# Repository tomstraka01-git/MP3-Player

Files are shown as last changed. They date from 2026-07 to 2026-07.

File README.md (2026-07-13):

<p align="center">
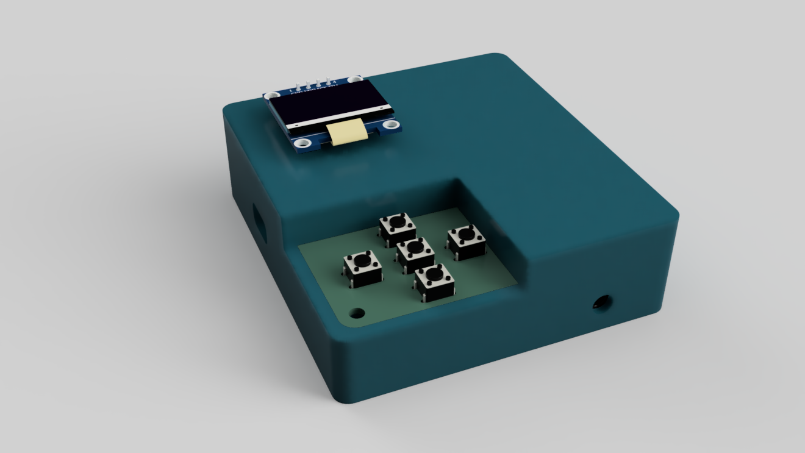
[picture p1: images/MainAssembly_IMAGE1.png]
  
</p>



# MP3-Player

## What is it?
MP3-Player is a DYI project made by me. It can:
- Play songs from a microSD card directly to your earphones.
- Stay on battery for multiple hours.
- Show you info about battery charge and info about song (time, song name, playing/not playing, etc.).
- Be controlled with 5 buttons.

## Why?
I like listening to music and making my own hardware/software projects, and i also wanted to learn more about how these things are made, so i chose to make one myself. 

## How to use?
1. Solder all the components to the custom PCB board.
2. 3D print the case and the battery hatch.
3. Screw the PCB securely into the case.
4. Download the firmware and flash it using the Arduino IDE.
5. Format a microSD card, add your `.mp3` or `.wav` songs directly to the root directory, and plug it into the reader.
6. Connect your charged Li-Po battery and you can now listen to your songs.

## Software
I wrote the main firmware in arduino ide c++. To flash the board, you must install arduino ide and the libraries i am using. Then connect the micro usb cable to the mcu, and flash the code. The code handles all the communications between the modules, plays the song to the PCM5102A and creates the ui, checks for buttons, checks battery etc.

## Electronics


I used a custom PCB, which takes power from a 3.7 Li-Po 450 mah (the battery should last for few hours) and passes it through a fast fuse for short circuit protection and diode for reverse connection protection. Then it goes to the rasberry pi pico 2 WH, which converts the power to stable 3.3V. The MCU reads the micro sd card reader module through spi, and then plays the song into the PCM5102A. It also displays all the info to the oled screen, and checks the five buttons for input. The five buttons have these features:
- Volume Down
- Volume Up
- Previous Song
- Next Song
- Play/Pause

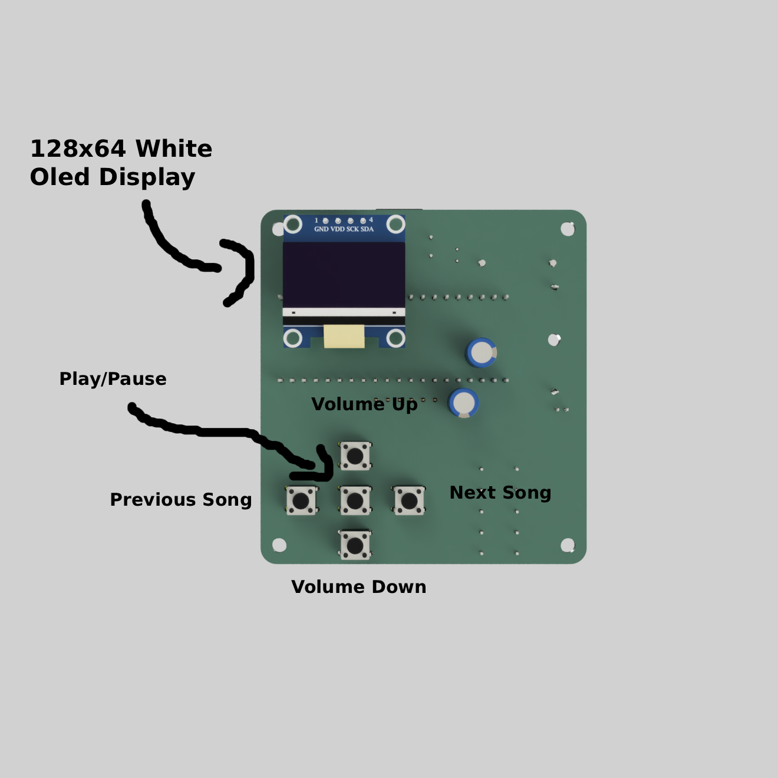
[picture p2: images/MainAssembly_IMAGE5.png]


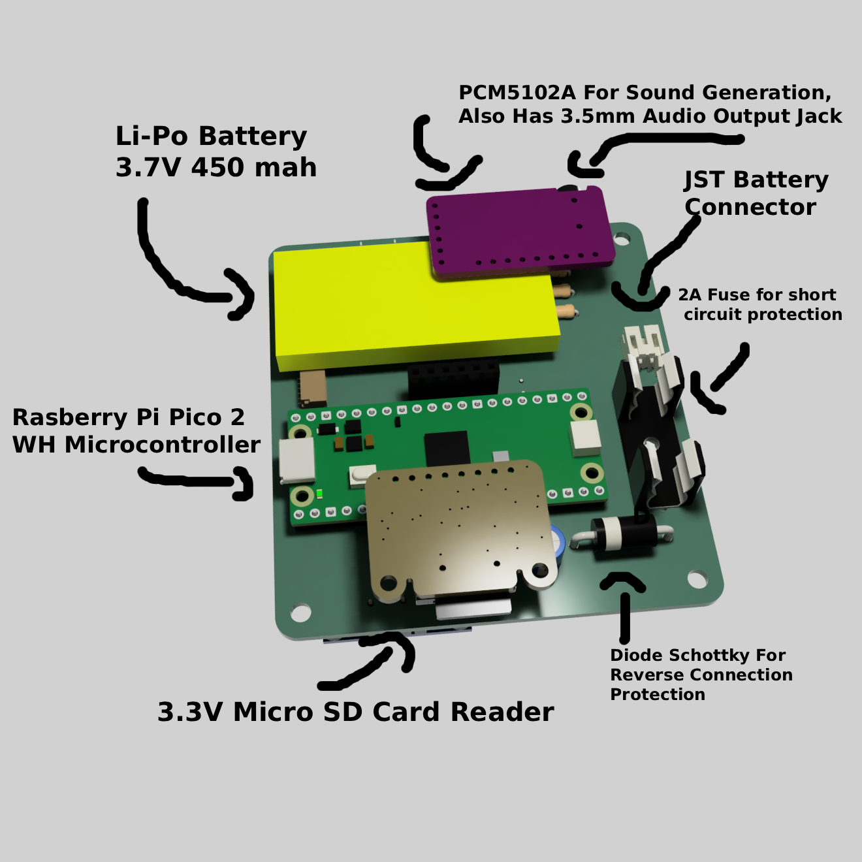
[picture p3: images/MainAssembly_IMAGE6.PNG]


## Features
- ### Has a 3.5mm audio jack output, you can connect your earphones to it and listen directly.
<p align="center">
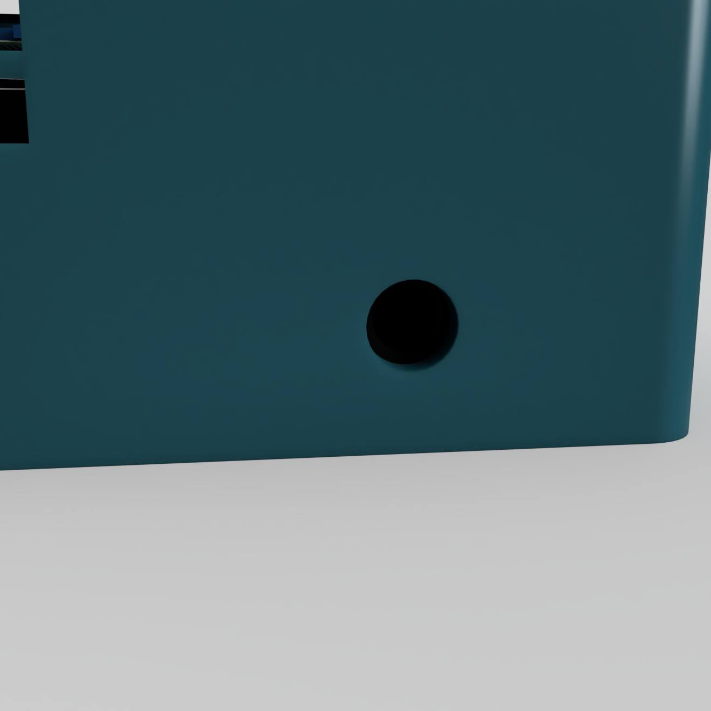
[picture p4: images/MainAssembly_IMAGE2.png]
  
</p>

- ### Has a micro SD card reader, put the micro SD card inside and listen to your songs.
<p align="center">
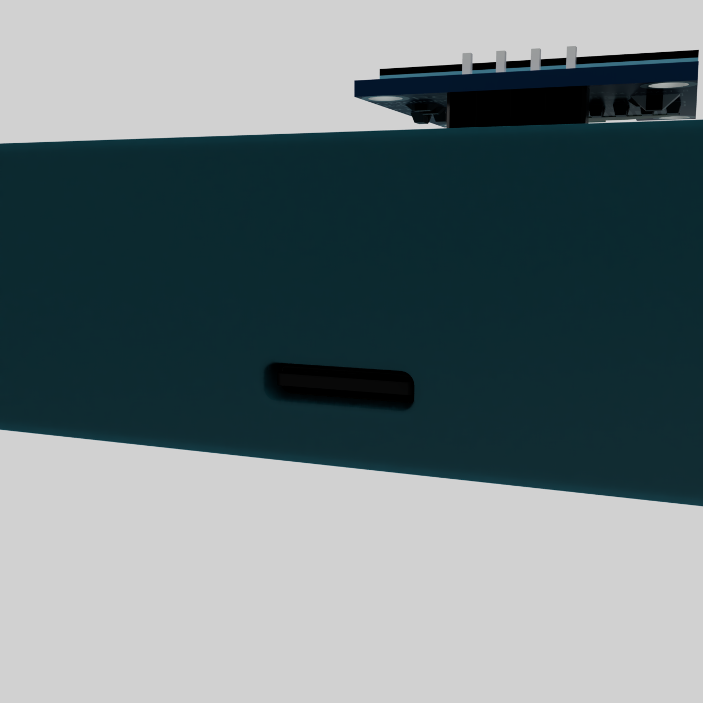
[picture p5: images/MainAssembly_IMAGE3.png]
  
</p>

- ### Has a micro USB port, so you can flash your own firmware or debug software issues.
<p align="center">
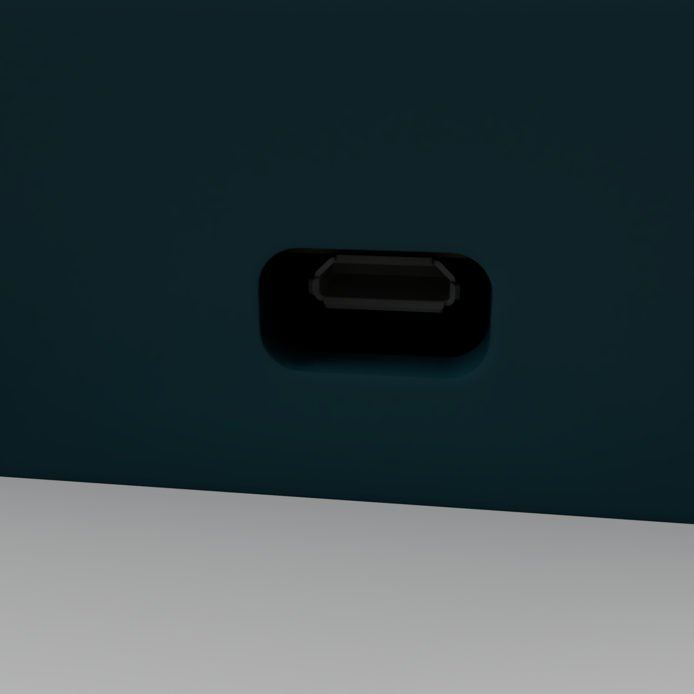
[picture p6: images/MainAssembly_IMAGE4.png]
  
</p>

# Bill of Materials (BOM)

| Item Name | Qty | Price (total) (USD) | Item Link | Notes |
|---|---|---|---|---|
| Resistor 10k | 5 | $0.24 | [Link](https://dratek.cz/arduino-platforma/7650-rezistor-10k-0.25-w-1.html) | Resistors for buttons, so that the circuit works |
| Button | 5 | $0.47 | [Link](https://dratek.cz/arduino-platforma/176310-mikrospinac-tlacitko-6-x-6-x-8-mm.html) | The buttons, used for skipping songs, changing volume, pausing, etc. |
| GY-PCM5102 I2S audio module | 1 | $4.61 | [Link](https://www.laskakit.cz/gy-pcm5102-i2s-audio-modul/) | The audio generator, changes digital sound to analog |
| 3.3V micro SD card module | 1 | $3.20 | [Link](https://www.laskakit.cz/laskakit-microsd-card-modul/) | Micro SD card reader, reads the micro SD card |
| OLED display 128x64 white | 1 | $7.86 | [Link](https://dratek.cz/arduino-platforma/3181-iic-i2c-oled-1-3-displej-128x64-bily.html) | OLED display, shows the user data like volume, info about songs, battery percent etc. |
| Resistor 100k | 1 | $0.05 | [Link](https://dratek.cz/arduino-platforma/7653-rezistor-100k-0.25-w-1.html) | Resistor for voltage divider, which steps down the voltage so the ADC can read it |
| Resistor 330k | 1 | $0.05 | [Link](https://dratek.cz/arduino-platforma/174965-metalizovany-rezistor-330k-0-25w-1.html) | Resistor for voltage divider, which steps down the voltage so the ADC can read it |
| Condensator 100µF 50V | 4 | $0.20 | [Link](https://dratek.cz/arduino-platforma/7825-kondenzator-100uf-50v.html) | Condensators, smooths the voltage and evens out current spikes |
| Fuse Fast 250V 2A | 10 | $0.19 | [Link](https://www.tme.eu/cz/details/zks-2a/pojistky-5x20mm-rychle/eska/520-620/) | Fast fuses — if there is a short circuit, the fuses blow and disconnect the battery from the circuit, protecting the battery and the person |
| Diode Schottky; THT; 40V; 3A; DO201AD; Ufmax: 0.475V | 2 | $0.64 | [Link](https://www.tme.eu/cz/details/1n5822-st/diody-schottky-tht/stmicroelectronics/1n5822/) | Diode, prevents opposite polarity battery connections |
| Dupont female pins | 1 | $0.33 | [Link](https://dratek.cz/arduino-platforma/913-dupont-dutinkova-lista-samice-samec.html?cv) | Used for plugging in the OLED display and other things |
| Dupont male pins | 1 | $0.15 | [Link](https://dratek.cz/arduino-platforma/1331-dupont-40pin-2-54-mm-kolikova-lista-rovna.html) | Same as above, but male version |
| JST 6-pin connector | 2 | $1.49 | [Link](https://www.tme.eu/cz/katalog/signalove-konektory-raster-1-00mm_112946/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) | SMD JST 6-pin connector, connects the micro SD card reader to the main PCB |
| JST 6-pin cable | 2 | $1.41 | [Link](https://dratek.cz/arduino-platforma/122186-jst-sh-1.0mm-6-pin-vodic-samice.html) | The cable for the SMD JST connector |
| Schurter fuse holder 10A 20x5mm | 2 | $2.28 | [Link](https://www.tme.eu/cz/details/0031.8211/pojistkova-pouzdra-do-pcb/schurter/) | Fuse holder — holds the fuse so it can be replaced when blown, no desoldering needed |
| JST battery terminal | 3 | $0.93 | [Link](https://www.tme.eu/cz/details/s2b-ph-k-s/signalove-konektory-raster-2-00mm/jst/s2b-ph-k-s-lf-sn/) | Battery terminal — the battery connects to it and distributes the power |
| Raspberry Pi Pico 2 WH | 1 | $9.71 | [Link](https://www.tme.eu/cz/details/sc1634/raspberry-pi-vestavene-systemy/raspberry-pi/raspberry-pi-pico-2-wh/) | The main brain of the system — reads the micro SD card, runs the UI menu, sends the sound output to the sound chip |
| Li-Po battery 3.7V 450mAh | 1 | $5.90 | [Link](https://dratek.cz/arduino-platforma/179445-lipol-baterie-502248-450mah-3-7v.html) | Shipping to Czech Republic |
| JLCPCB PCB | 5 | $3.20 | [Link](https://cart.jlcpcb.com/quote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) | Shipping to Czech Republic |
| Shipping — Dratek.cz | 1 | $4.00 | [Link](https://www.dratek.cz) | Shipping to Czech Republic |
| Shipping — TME.eu | 1 | $8.47 | [Link](https://www.tme.eu/) | |
| Shipping — LaskaKit | 1 | $3.76 | [Link](https://www.laskakit.cz) | |
| Shipping — JLCPCB | 1 | $12.00 | [Link](https://jlcpcb.com/) | |
| **Total Price (USD)** | | **$65.82** | | |

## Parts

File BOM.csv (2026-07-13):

Item Name | Qty | Price (total) (USD) | Item link | Notes
Resistor 10k | 5 | $0.24 | https://dratek.cz/arduino-platforma/7650-rezistor-10k-0.25-w-1.html | Resistors for buttons, so that the circuit works
Button | 5 | $0.47 | https://dratek.cz/arduino-platforma/176310-mikrospinac-tlacitko-6-x-6-x-8-mm.html | The buttons, used for skipping songs, changing volume, pausing, etc.
GY-PCM5102 I2S audio module | 1 | $4.61 | https://www.laskakit.cz/gy-pcm5102-i2s-audio-modul/ | The audio generator, changes digital sound to analog
3.3v micro sd card module | 1 | $3.20 | https://www.laskakit.cz/laskakit-microsd-card-modul/ | Micro sd card reader, reads the micro sd card
Oled display 128x64 white | 1 | $7.86 | https://dratek.cz/arduino-platforma/3181-iic-i2c-oled-1-3-displej-128x64-bily.html | Oled display, shows the user data like volume, info about songs, battery percent etc.
Resistor 100k | 1 | $0.05 | https://dratek.cz/arduino-platforma/7653-rezistor-100k-0.25-w-1.html | Resistor for voltage divider, wich stepdowns the voltage so the adc can read it
Resistor 330k | 1 | $0.05 | https://dratek.cz/arduino-platforma/174965-metalizovany-rezistor-330k-0-25w-1.html | Resistor for voltage divider, wich stepdowns the voltage so the adc can read it
Condensator 100microfarad 50v | 4 | $0.20 | https://dratek.cz/arduino-platforma/7825-kondenzator-100uf-50v.html | Condensators, smooths the voltage and smoothes out current spikes
Fuse Fast 250v 2A | 10 | $0.19 | https://www.tme.eu/cz/details/zks-2a/pojistky-5x20mm-rychle/eska/520-620/ | Fast fuses, if there is a short circuit, the fuses will go of and disconnect the battery from the circuit, saving the battery and the person
Diode Schottky; THT; 40V; 3A; DO201AD; Ufmax: 0,475V | 2 | $0.64 | https://www.tme.eu/cz/details/1n5822-st/diody-schottky-tht/stmicroelectronics/1n5822/ | Diode, prevents opposite polarity battery connections
Dupont female pins | 1 | $0.33 | https://dratek.cz/arduino-platforma/913-dupont-dutinkova-lista-samice-samec.html?cv | I will use these dupont pins for plugging in oled display and other things
Dupont male pins | 1 | $0.15 | https://dratek.cz/arduino-platforma/1331-dupont-40pin-2-54-mm-kolikova-lista-rovna.html | Same as before, but they are male version
JST 6 pin connector | 2 | $1.49 | https://www.tme.eu/cz/katalog/signalove-konektory-raster-1-00mm_112946/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 | SMD jst 6 pin connector, connects the micro sd card reader to the main pcb
JST 6 pin cable | 2 | $1.41 | https://dratek.cz/arduino-platforma/122186-jst-sh-1.0mm-6-pin-vodic-samice.html | The cable for the smd jst connector
Shurter Fuse holder 10A 20x5mm | 2 | $2.28 | https://www.tme.eu/cz/details/0031.8211/pojistkova-pouzdra-do-pcb/schurter/ | Fuse holder, holds the fuse, so when the fuse goes off, you can juts replace the fuse, no desoldering
JST battery teminal | 3 | $0.93 | https://www.tme.eu/cz/details/s2b-ph-k-s/signalove-konektory-raster-2-00mm/jst/s2b-ph-k-s-lf-sn/ | Battery terminal, the battery connects to it and distributes the power
Rasberry pi pico 2 WH | 1 | $9.71 | https://www.tme.eu/cz/details/sc1634/raspberry-pi-vestavene-systemy/raspberry-pi/raspberry-pi-pico-2-wh/ | The main brain of the system, reads the micro sd card, runs the ui menu, sends the sound output to the sound chip.
Li-Po battery 3.7v 450mah | 1 | $5.90 | https://dratek.cz/arduino-platforma/179445-lipol-baterie-502248-450mah-3-7v.html | Shipping to czech republic
JLCPCB PCB | 5 | $3.20 | https://cart.jlcpcb.com/quote?stencilLayer=2&stencilWidth=100&stencilLength=100&stencilCounts=5&plateType=1 | Shipping to czech republic
Shipping Dratek.cz | 1 | $4.00 | https://www.dratek.cz | Shipping to czech republic
Shipping tme.eu | 1 | $8.47 | https://www.tme.eu/
Shipping laskakit | 1 | $3.76 | https://www.laskakit.cz
Shipping JLCPCB | 1 | $12.00 | https://jlcpcb.com/
Total Price (USD) |  | $65.82

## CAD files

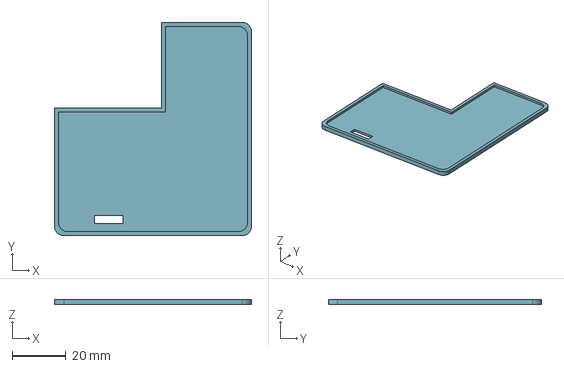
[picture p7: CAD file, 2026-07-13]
cad/MainHatch3DPrint.step
73.5 x 79.6 x 2.00 mm

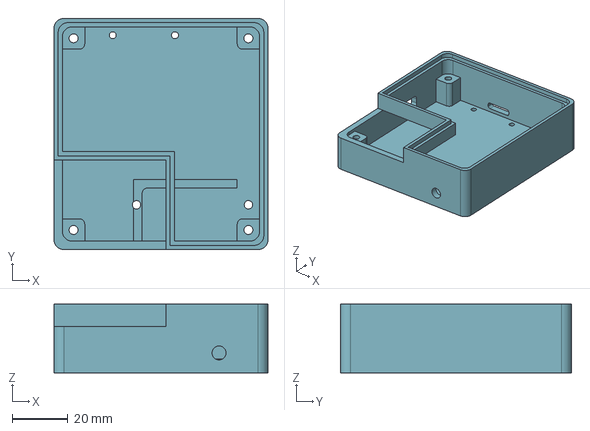
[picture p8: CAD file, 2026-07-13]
cad/MainCase3DPrint.step
76.5 x 82.6 x 24.5 mm

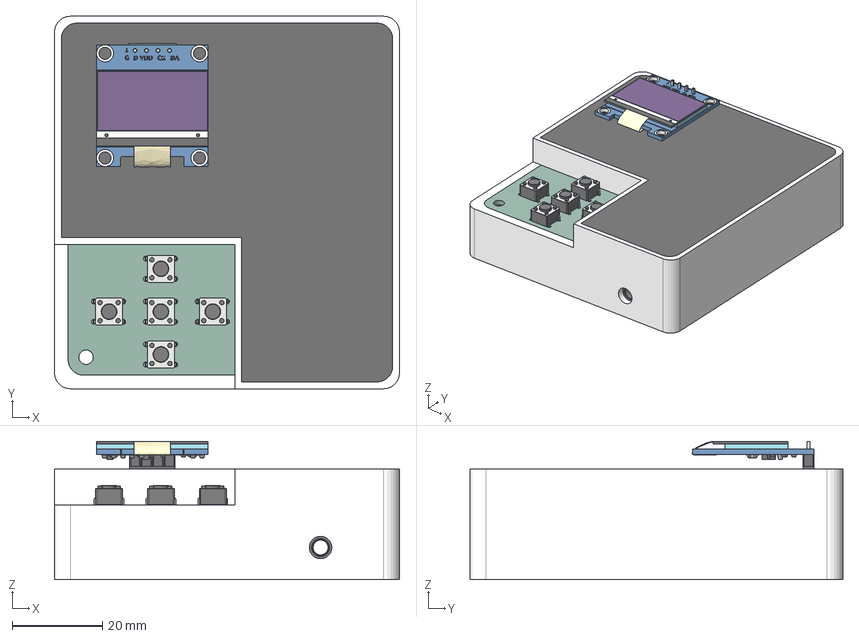
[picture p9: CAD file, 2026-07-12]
cad/MainAssembly.step
76.5 x 82.6 x 30.6 mm

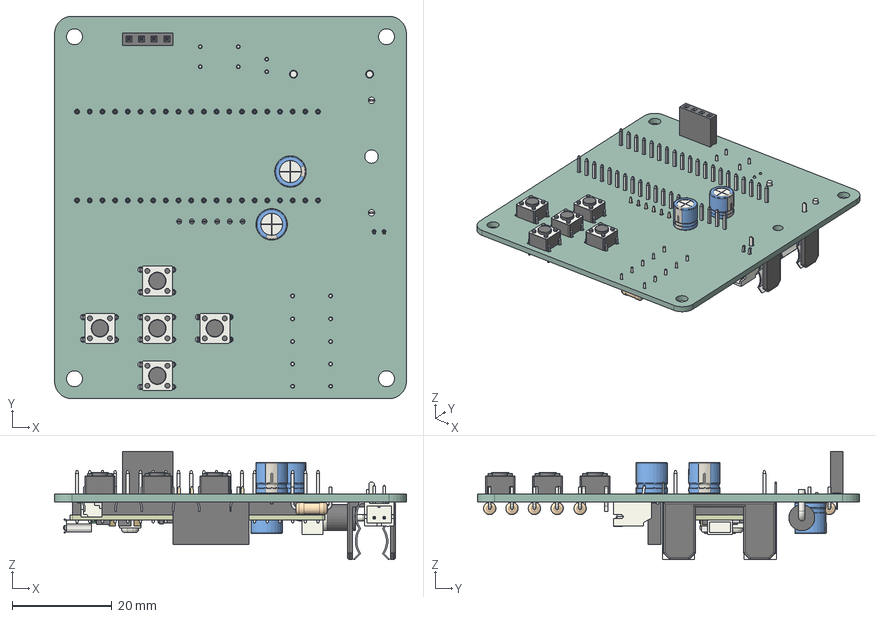
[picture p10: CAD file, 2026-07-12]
cad/PCB-MP3.step
70.5 x 76.6 x 21.7 mm
SW_PUSH_6mm_h4.3mm x 5
CP_Radial_D63mm_P250mm x 3
PinSocket_1x04_P2.54mm_Vertical
R_Axial_DIN0207_L63mm_D25mm_P762mm_Horizontal x 7
RaspberryPi_Pico_H_Module_KiCad
RaspberryPi_Pico_Header_DIP-40_H2.54mm_KiCad
JST_S2B_PH_K
JST_SH_SM06B-SRSS-TB_1x06-1MP_P1.00mm_Horizontal
D_DO-201AD_P15.24mm_Horizontal
PinSocket_1x06_P2.54mm_Vertical
A_Schurter_0031_8201
PCB-MP3-Player_PCB

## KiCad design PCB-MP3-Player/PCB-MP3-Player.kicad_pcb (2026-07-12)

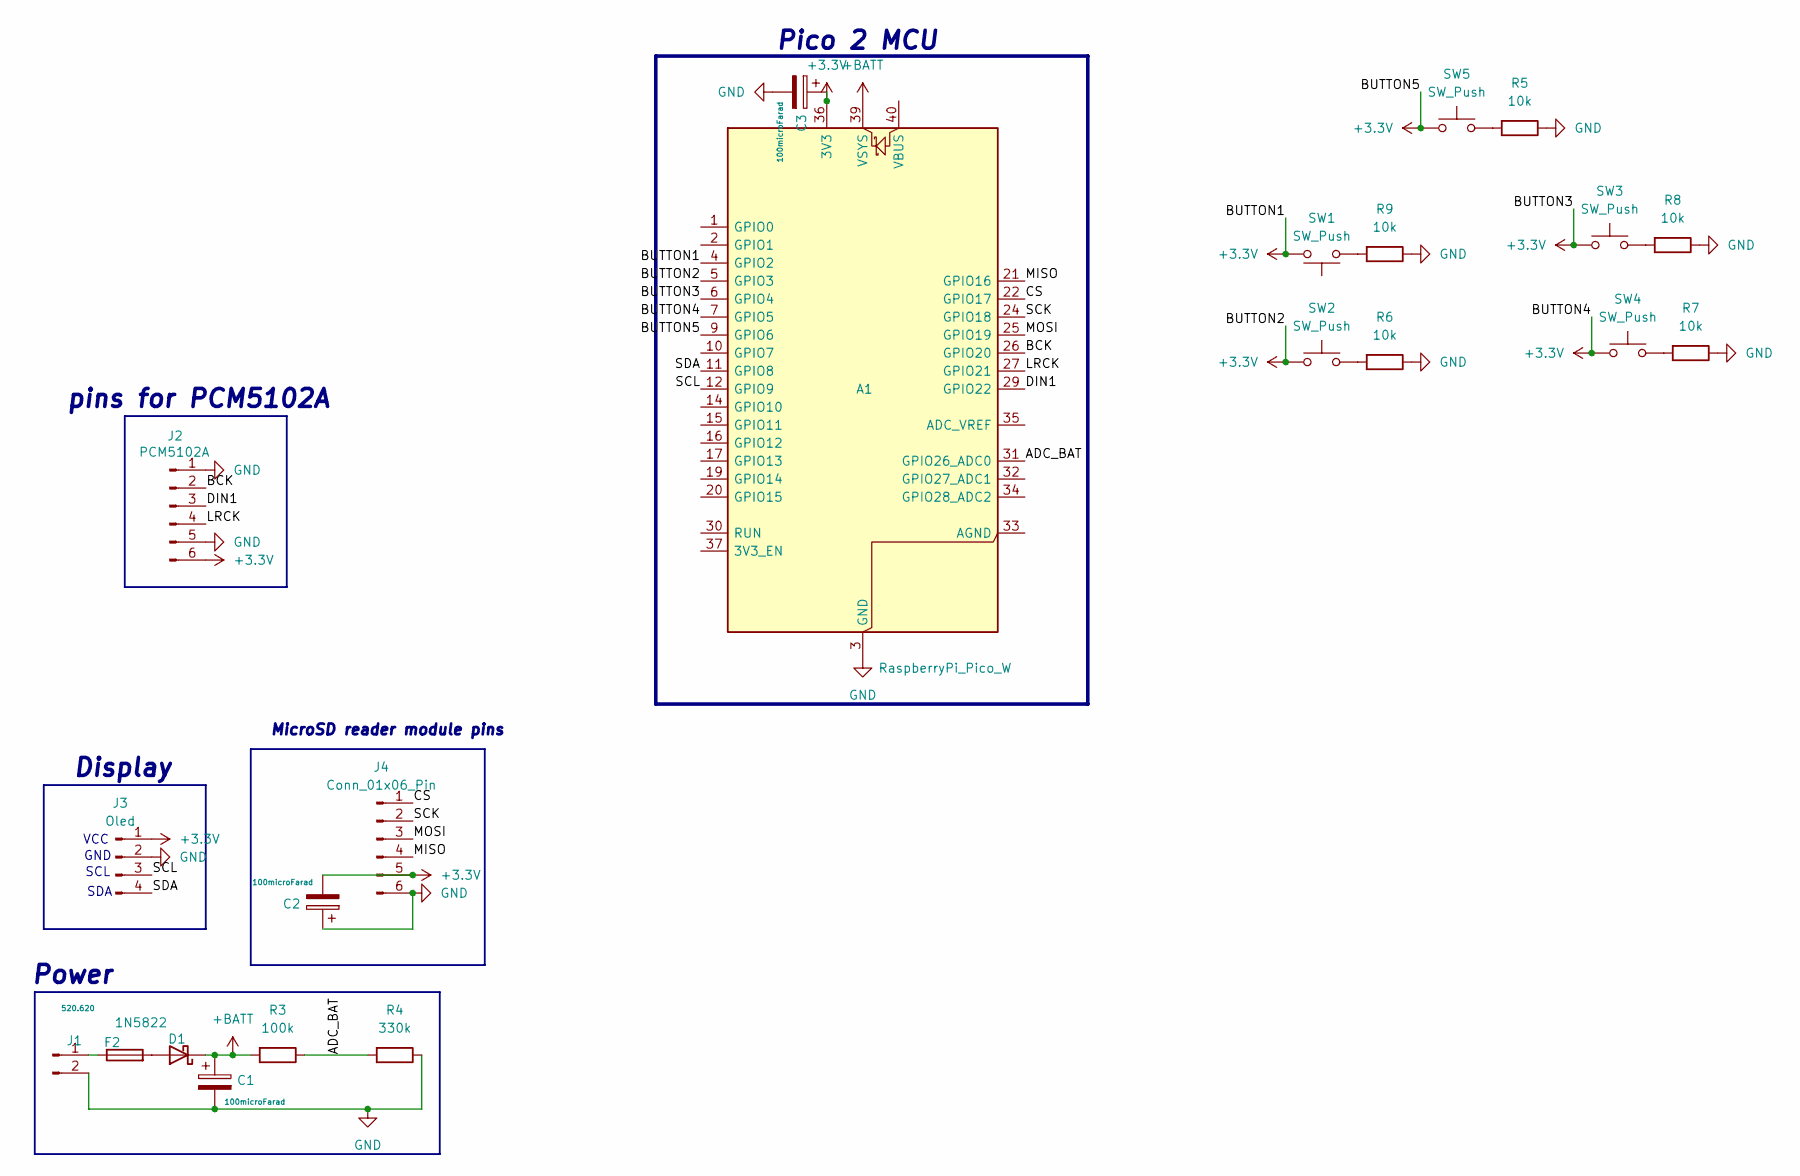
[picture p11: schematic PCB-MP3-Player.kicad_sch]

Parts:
A1: RaspberryPi_Pico_W; RaspberryPi_Pico_Common_THT
C1, C2, C3: 100microFarad; CP_Radial_D6.3mm_P2.50mm
D1: 1N5822; D_DO-201AD_P15.24mm_Horizontal
F2: 520.620; Fuseholder_Cylinder-5x20mm_Schurter_0031_8201_Horizontal_Op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
J1: Conn_01x02_Pin; JST_PH_S2B-PH-K_1x02_P2.00mm_Horizontal
J2: PCM5102A; PinSocket_1x06_P2.54mm_Vertical
J3: Oled; PinSocket_1x04_P2.54mm_Vertical
J4: Conn_01x06_Pin; JST_SH_SM06B-SRSS-TB_1x06-1MP_P1.00mm_Horizontal
R3: 100k; R_Axial_DIN0207_L6.3mm_D2.5mm_P7.62mm_Horizontal
R4: 330k; R_Axial_DIN0207_L6.3mm_D2.5mm_P7.62mm_Horizontal
R5, R6, R7, R8, R9: 10k; R_Axial_DIN0207_L6.3mm_D2.5mm_P7.62mm_Horizontal
SW1, SW2, SW3, SW4, SW5: SW_Push; SW_PUSH_6mm_H4.3mm

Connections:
+3.3V: A1.4 (GPIO2), A1.5 (GPIO3), A1.6 (GPIO4), A1.7 (GPIO5), A1.9 (GPIO6), A1.36 (3V3), C2.2, C3.1, J2.6, J3.1, J4.5, SW1.2, SW2.1, SW3.1, SW4.1, SW5.1
+BATT: A1.39 (VSYS), C1.1, D1.1 (K), R3.2
/ADC_BAT: A1.31 (GPIO26_ADC0), R3.1, R4.2
/BCK: A1.26 (GPIO20), J2.2
/CS: A1.22 (GPIO17), J4.1
/DIN1: A1.29 (GPIO22), J2.3
/LRCK: A1.27 (GPIO21), J2.4
/MISO: A1.21 (GPIO16), J4.4
/MOSI: A1.25 (GPIO19), J4.3
/SCK: A1.24 (GPIO18), J4.2
/SCL: A1.12 (GPIO9), J3.3
/SDA: A1.11 (GPIO8), J3.4
GND: A1.3 (GND), A1.8 (GND), A1.13 (GND), A1.18 (GND), A1.23 (GND), A1.28 (GND), A1.38 (GND), C1.2, C2.1, C3.2, J1.2, J2.1, J2.5, J3.2, J4.6, R4.1, R5.1, R6.1, R7.1, R8.1, R9.1
unnamed: D1.2 (A), F2.2
unnamed: F2.1, J1.1
unnamed: R5.2, SW5.2
unnamed: R6.2, SW2.2
unnamed: R7.2, SW4.2
unnamed: R8.2, SW3.2
unnamed: R9.2, SW1.1

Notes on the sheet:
SCL
Display
Pico 2 MCU
pins for PCM5102A
VCC
GND
MicroSD reader module pins
Power
SDA

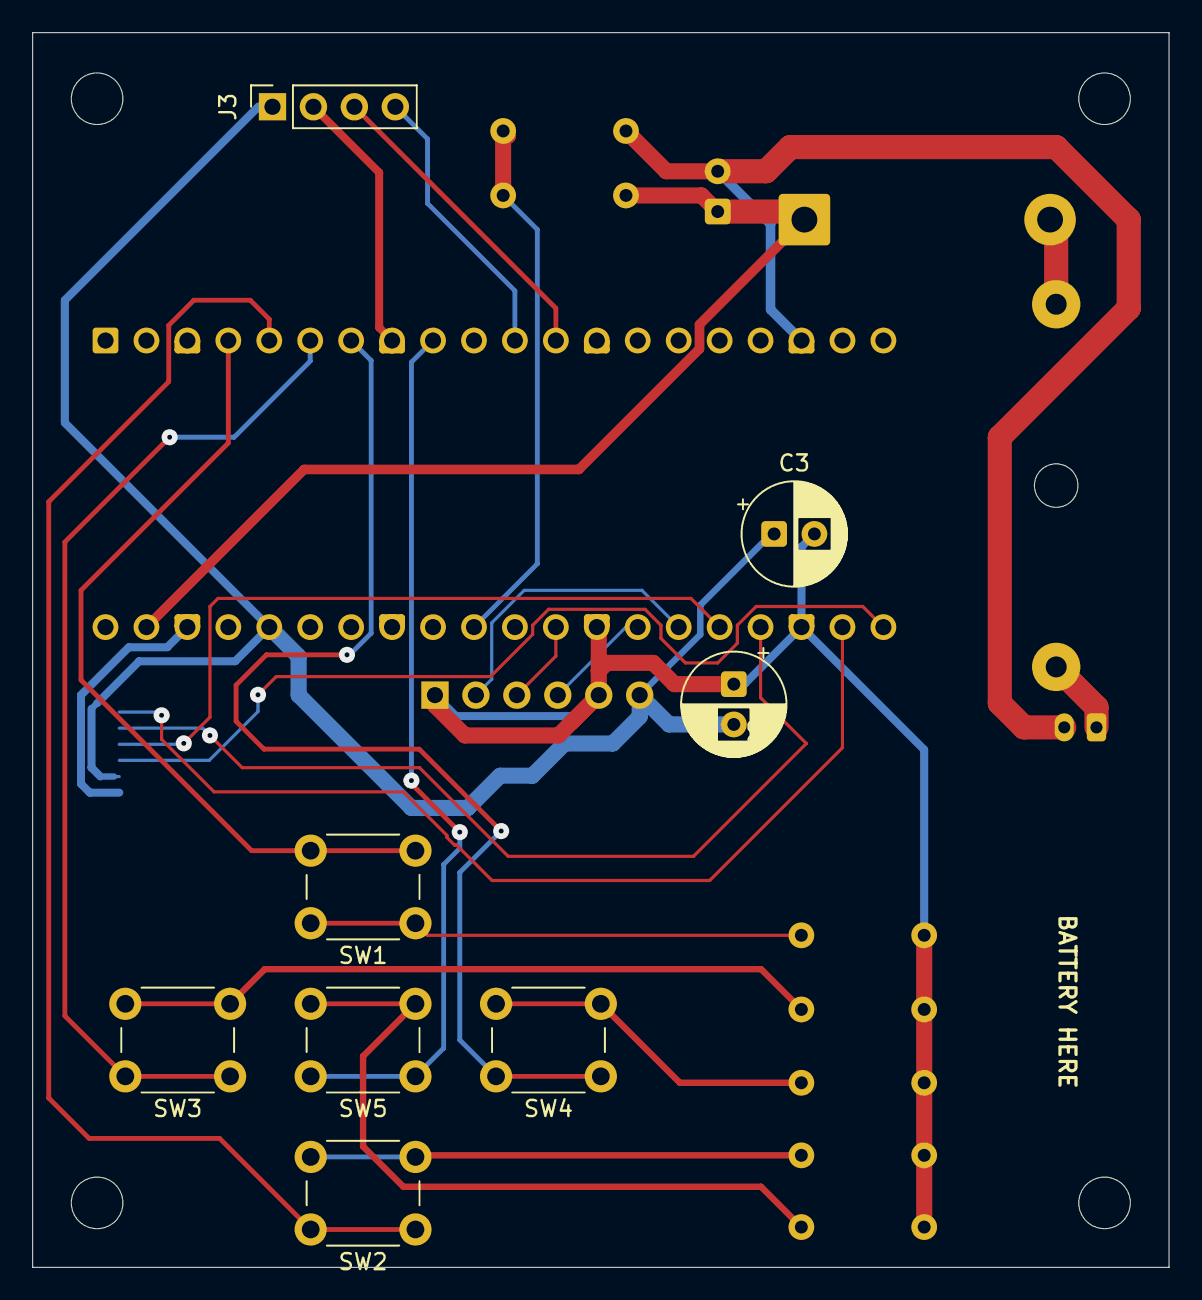
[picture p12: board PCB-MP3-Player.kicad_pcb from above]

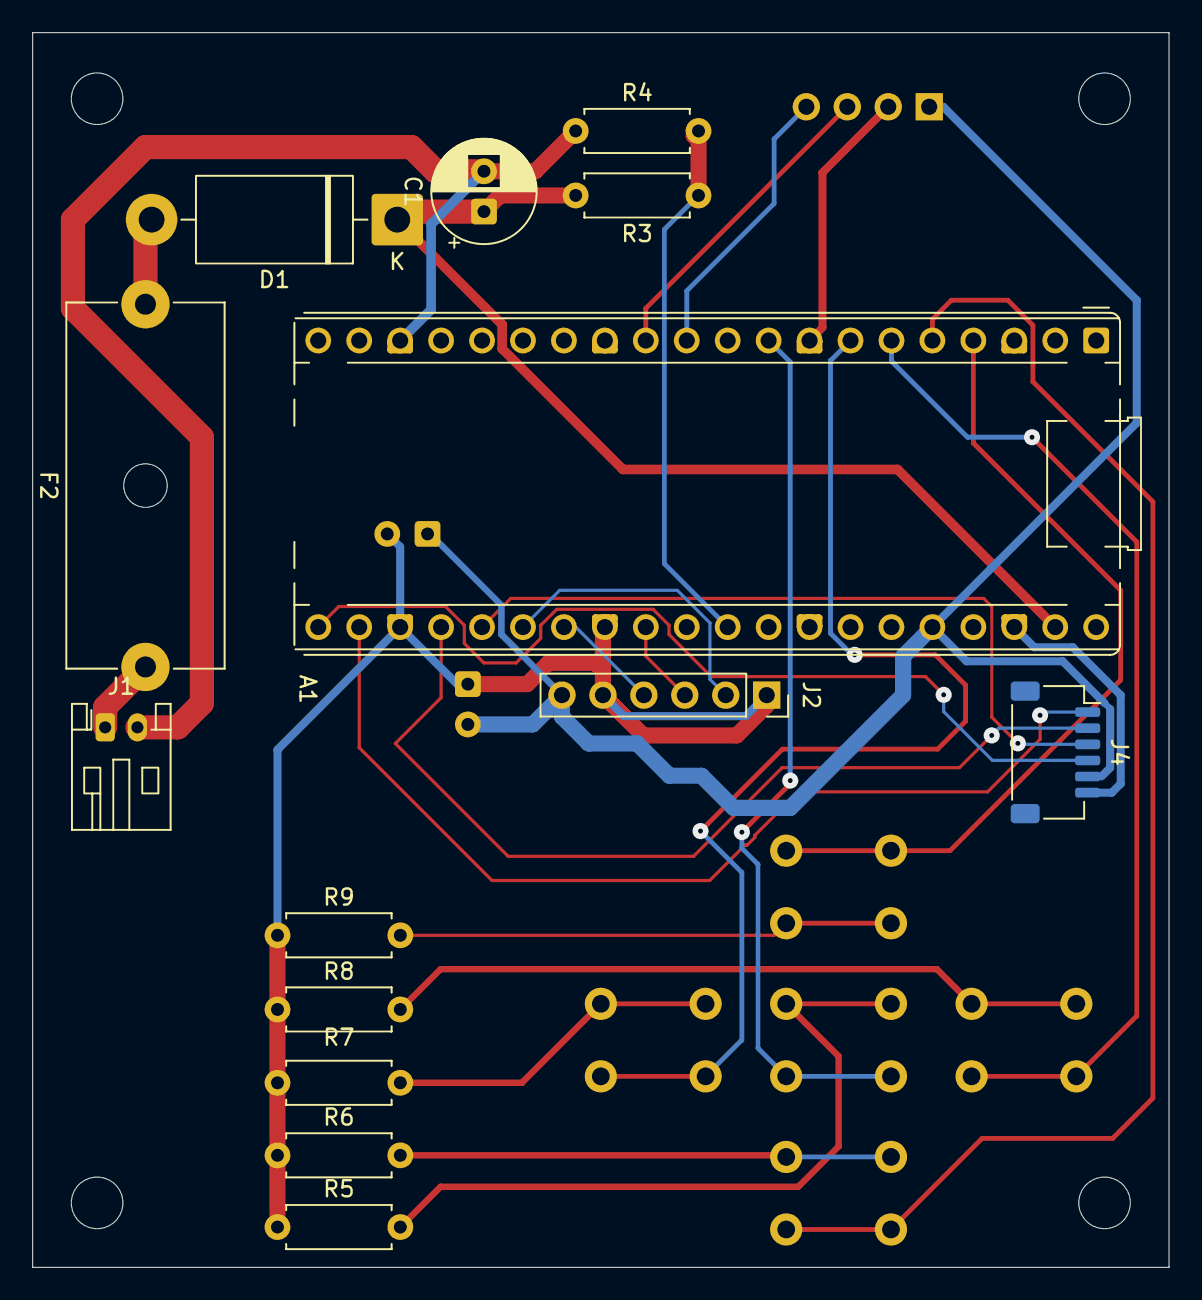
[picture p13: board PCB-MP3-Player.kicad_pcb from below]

Board: 2 copper layers, 70.5 x 76.6 mm, 22 parts (14 on the bottom side), 20 nets.

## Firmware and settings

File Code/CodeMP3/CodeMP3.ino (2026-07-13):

#include <SPI.h>
#include <SD.h>
#include <I2S.h>
#include "AudioFileSourceSD.h"
#include "AudioGeneratorMP3.h"
#include "AudioGeneratorWAV.h"
#include "AudioOutputI2S.h"

#include <vector>

#include <Adafruit_GFX.h>
#include <Adafruit_SSD1306.h>
#include <Wire.h>

#define SCREEN_WIDTH 128
#define SCREEN_HEIGHT 64
#define OLED_RESET -1


Adafruit_SSD1306 display(SCREEN_WIDTH, SCREEN_HEIGHT, &Wire, OLED_RESET);


#define BCK_PIN 20
#define LRCK_PIN 21 
#define DIN_PIN 22

#define SAMPLE_RATE 44100
#define AMPLITUDE   32767
float volume = 0.50f;
float volume_inc = 0.05f;

bool is_playing = false;

// 1 for volume up, 2 for volume down by 10%. 3 for skipping through playlist left, 4 for right. 5 for play or pause.
const int NUM_BUTTONS = 5;
const int buttonPins[NUM_BUTTONS] = {2, 3, 4, 5, 6}; 

int buttonStates[NUM_BUTTONS] = {HIGH, HIGH, HIGH, HIGH, HIGH}; 
int lastButtonStates[NUM_BUTTONS] = {HIGH, HIGH, HIGH, HIGH, HIGH}; 
unsigned long lastDebounceTimes[NUM_BUTTONS] = {0, 0, 0, 0, 0};
unsigned long debounceDelay = 50; // Debounce time in milliseconds

const int chipSelect = 17;
#define SPI0_MISO 16
#define SPI0_MOSI 19
#define SPI0_SCK  18

AudioOutputI2S *out;
AudioFileSourceSD *file = NULL;
AudioGeneratorMP3 *mp3 = NULL;
AudioGeneratorWAV *wav = NULL;

std::vector<String> fileList;
int file_index = 0;

void readButtons();
void play_file(String fileName);
void stop_audio();
void updateOled();
void advance_track();
float calculate_adc();

// adc variables
#define GPIO_PIN_ADC 26

float r1 = 100000.0f;
float r2 =330000.0f;

// Vout = Vin × R2 / (R1 + R2)
// Vout = vin_adc / (R2 / (R1 + R2)) = vin_adc * 0.76

float multiply_adc_constant = r2 / (r1 + r2);

int last_adc_time = 0;

float calculate_adc() {
  int raw = analogRead(GPIO_PIN_ADC);
  float v_out = (raw * 3.3f) / 4096.0f; 
  
  float v_in = v_out * ((r1 + r2) / r2); 
  return v_in;
}

float voltage = 0.0f;

void setup() {
  for (int i = 0; i < NUM_BUTTONS; i++) { 
    pinMode(buttonPins[i], INPUT_PULLUP);
  }

  Serial.begin(115200);
 

  SPI.setRX(SPI0_MISO);
  SPI.setTX(SPI0_MOSI);
  SPI.setSCK(SPI0_SCK);

  Serial.print("SD Starting... ");
  if (!SD.begin(chipSelect)) {
    Serial.println("SD Failed");

  } else {
    Serial.println("SD Done");
  }


  Wire.setSDA(8);
  Wire.setSCL(9);
  if(!display.begin(SSD1306_SWITCHCAPVCC, 0x3C)) { 
    Serial.println(F("SSD1306 allocation failed"));
  }
  display.clearDisplay();
  display.display();

  out = new AudioOutputI2S();
  out->SetPinout(BCK_PIN, LRCK_PIN, DIN_PIN);
  out->SetGain(volume);

  File root = SD.open("/");
  if (root) {
    while (true) {
      File entry = root.openNextFile();
      if (!entry) break;

      if (entry.isDirectory()) {
        entry.close();
        continue;
      }

      String fileName = entry.name();
      String lowerName = fileName;
      lowerName.toLowerCase();

      if (lowerName.endsWith(".mp3") || lowerName.endsWith(".wav")) {
        fileList.push_back("/" + fileName);
      }
      entry.close();
    }
    root.close();
  }

  if (fileList.size() > 0) {
    play_file(fileList[file_index]);
  } else {
    Serial.println("No audio files found.");
    updateOled();
  }
}

void loop() {
  readButtons();
  

  

  if (millis() - last_adc_time > 1000) {
    last_adc_time = millis();
    voltage = calculate_adc();
    updateOled();

  }
  if (is_playing) {
    if (mp3 && mp3->isRunning()) {
      if (!mp3->loop()) { 
 
        advance_track(); 
      }
    } else if (wav && wav->isRunning()) {
      if (!wav->loop()) { 

        advance_track();
      }
    }
  }
}

void advance_track() {
  if (fileList.size() > 0) {
    file_index = (file_index + 1) % fileList.size();

    play_file(fileList[file_index]);

  } else {
    stop_audio();
  }
}
void updateOled() {
  display.clearDisplay();
  display.setTextSize(1);
  display.setTextColor(SSD1306_WHITE);
  display.setCursor(0, 0);

  // Top Row: song counter

  if (fileList.size() > 0) {
    display.printf("Track: %d / %d", file_index + 1, fileList.size());
  } else { 
    display.println("No files found");
  }
  
  // Dividing line
  display.drawFastHLine(0, 10, 128, SSD1306_WHITE);

  // Midle row: Song title
  display.setCursor(0, 22);
  if (fileList.size() > 0) {
    String name = fileList[file_index].substring(1);
  
  
    if (name.length() > 20) {
        name = name.substring(0, 17) + "...";
      }
      
    display.print(name);
  }

  // Dividing line above the status bar
  display.drawFastHLine(0, 48, 128, SSD1306_WHITE);
  
  // Bottom row: status bar

  display.setCursor(0, 54);
  display.printf("Vol:%d%% %s", (int)(volume * 100), is_playing ? "PLAY" : "PAUS");

  // Voltage readings right

  display.setCursor(85, 54);
  display.printf("%.2fV", voltage);
  
  display.display();


}

void stop_audio() {
  if (mp3) { mp3->stop(); delete mp3; mp3 = NULL; }
  if (wav) { wav->stop(); delete wav; wav = NULL; }
  if (file) { delete file; file = NULL; }
}

void play_file(String fileName) {
  stop_audio();
  
  file = new AudioFileSourceSD(fileName.c_str());
  String lowerName = fileName;
  lowerName.toLowerCase();

  if (lowerName.endsWith(".wav")) {
    Serial.print("Playing wav: ");
    Serial.println(fileName);
    wav = new AudioGeneratorWAV();
    if (wav->begin(file, out)) {
      is_playing = true;
    }
  } else if (lowerName.endsWith(".mp3")) {
    Serial.print("Playing MP3: ");
    Serial.println(fileName);
    mp3 = new AudioGeneratorMP3();
    if (mp3->begin(file, out)) {
      is_playing = true;
    }
  }
  
  updateOled();
}

void readButtons() {
  for (int i = 0; i < NUM_BUTTONS; i++) {
    
    int reading = digitalRead(buttonPins[i]);

    if (reading != lastButtonStates[i]) {
      lastDebounceTimes[i] = millis();

    }

    if ((millis() - lastDebounceTimes[i]) > debounceDelay) {
      if (reading != buttonStates[i]) {
        buttonStates[i] = reading;

        // Buttons was pressed, i am using input pullup so lowe means pressed
        if (buttonStates[i] == LOW) {
          switch (i) {
            case 0: // volume up
              volume += volume_inc;
              if (volume > 1.0f) volume = 1.0f;
              out->SetGain(volume);
              updateOled();
              break;

            case 1: // volume down
              volume -= volume_inc;
              if (volume < 0.0f) volume = 0.0f;
              out->SetGain(volume); 
              updateOled();
              break;

            case 2: // play prev
              if (fileList.size() > 0) {
                file_index--;
                if (file_index < 0) {file_index = fileList.size() - 1;}
                play_file(fileList[file_index]);
              }
              break;
            
            case 3: // play next
              if (fileList.size() > 0) {
                file_index = (file_index + 1) % fileList.size();
                play_file(fileList[file_index]);
              }
              break;
            
            case 4: // pause/play
              is_playing = !is_playing;
              updateOled();
              break;

              
            } 
        }
      } 
    } 
    lastButtonStates[i] = reading;
  } 
} 

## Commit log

2026-06-20 first commit, added some components to the pcb. Started thinking about the project
    [PCB-MP3-Player.kicad_pcb, PCB-MP3-Player.kicad_sch]
2026-06-22 connected components together
    [PCB-MP3-Player.kicad_sch]
2026-07-02 pcb changes
    [PCB-MP3-Player.kicad_pcb, PCB-MP3-Player.kicad_sch]
2026-07-04 connected oled
    [PCB-MP3-Player.kicad_pcb, PCB-MP3-Player.kicad_sch]
2026-07-09 Devlog #6
    [PCB-MP3-Player.kicad_pcb, PCB-MP3-Player.stl, PCB-MP3.step]
2026-07-11 Devlog 7
    [PCB-MP3-Player.kicad_pcb, PCB-MP3-Player.kicad_sch, PCB-MP3.step]
2026-07-12 Adding renders, readme, etc.
    [MainAssembly.step, PCB-MP3-Player.kicad_pcb, PCB-MP3-Player.kicad_sch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]
2026-07-13 Added cad files for 3D printing
    [MainCase3DPrint.step, MainHatch3DPrint.step]
2026-07-13 added gerbers
    [PCB-MP3-Player-B_Cu.gbr, PCB-MP3-Player-B_Mask.gbr, PCB-MP3-Player-B_Paste.gbr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]
2026-07-13 forgot to make the gerbers into zip, added it into zip
2026-07-13 forgot to add pcb to bom, added it now
    [BOM.csv]
